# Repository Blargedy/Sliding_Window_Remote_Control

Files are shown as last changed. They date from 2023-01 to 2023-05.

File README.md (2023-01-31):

# Sliding Window Remote Control
WIP



### BoM
* linear actuator x1
* L298N H-bridge motor driver x1 [Amazon](https://www.amazon.ca/gp/product/B07D1HP3SJ/ref=ppx_yo_dt_b_search_asin_title?ie=UTF8&psc=1)
* 12v power supply with 5.5mm barrel jack x1 [Amazon](https://www.amazon.ca/gp/product/B085ZZ86ZJ/ref=ppx_yo_dt_b_search_asin_title?ie=UTF8&psc=1)
* limit switch x1 [Amazon](https://www.amazon.ca/gp/product/B07YKH3TDR/ref=ppx_yo_dt_b_search_asin_title?ie=UTF8&psc=1)
* SPST-mom button x1 [Amazon](https://www.amazon.ca/gp/product/B07Q6C3NSN/ref=ppx_yo_dt_b_search_asin_title?ie=UTF8&psc=1)
* Panic cutoff button x1 [Amazon](https://www.amazon.ca/gp/product/B07WTL3KPB/ref=ppx_yo_dt_b_search_asin_title?ie=UTF8&psc=1)
* SPDT-mom switch x1 [Amazon](https://www.amazon.ca/gp/product/B01LYGWWHA/ref=ppx_yo_dt_b_search_asin_title?ie=UTF8&psc=1)
* SPDT-latching switch x1 [Amazon](https://www.amazon.ca/gp/product/B01BTTOEQ6/ref=ppx_yo_dt_b_search_asin_title?ie=UTF8&psc=1)
* 5.5mm x 2.1mm barrel jack connector [Amazon](https://www.amazon.ca/gp/product/B092Z6ZG3V/ref=ppx_yo_dt_b_search_asin_title?ie=UTF8&psc=1)
* power button x1 [Amazon](https://www.amazon.ca/gp/product/B08225LGRT/ref=ppx_yo_dt_b_search_asin_title?ie=UTF8&psc=1)
* 12v A4x20 fan x1 [Amazon](https://www.amazon.ca/gp/product/B071W93333/ref=ppx_yo_dt_b_search_asin_title?ie=UTF8&psc=1)
* panic button x1 [Amazon](https://www.amazon.ca/gp/product/B07WTL3KPB/ref=ppx_yo_dt_b_search_asin_title?ie=UTF8&psc=1)
* Arduino Wemos D1 Mini x1 [Amazon](https://www.amazon.ca/gp/product/B07WWFND3B/ref=ppx_yo_dt_b_search_asin_title?ie=UTF8&psc=1)
* 2 port wago x1
* 3 port wago x1
* 5 port wago x2
* 2 port microfit-3 connectors and crimps x2
* Dupont headers and crimps
* ferrule crimps
* M3 hardware
* M3 heat inserts (4mmH x 5mmD) x4
* wires

## Part printing
Clearances were designed for ABS/ASA shrinkages, but the parts can be made of basically any filament

## Electronics
1. solder and crimp electric box
2. Crimp linear actuator



## Software Configuration
1. Install arduino ide
2. Download  Wemos drivers from https://www.wemos.cc/en/latest/ch340_driver.html
3. Create a new folder somewhere and extract the contents of the driver zip into this new folder
4. run `SETUP.EXE`
5. Click on `INSTALL`



6. In arduino IDE click on `File` then `Prefereces...`



7. under `Additional Boards Manager URLs:` paste ```http://arduino.esp8266.com/stable/package_esp8266com_index.json```



8. Click on `Sketch`, then `Include Library` then `Manage Libraries`, or press the key combination `Ctr+Shift+I`.



9. Search for a library called `ESP8266 microgear` and click `INSTALL`.



10. Click on `Tools`, then `Board` then `Board Manager` or press the key combination `Ctr+Shift+B`.



11. Search for `ESP8266` and install the board



12. Make sure the switch that controls the motor driver 5v supply is shut off and/or you unplug the unit, or you'll damage the driver or your pc or both

13. Plug in the D1 mini with a micro-usb cable

14. Click on `Select Board` and select the `Unknown COMx`.



15. Search for `d1` and select `LOLIN(WEMOS) D1 R2 & mini`



16. Copy the folder `wifi_passwords` to your arduino library folder (under `Documents > Arduino > libraries` by default)



17. Edit wifi_passwords.h to fill in your wifi name and password, replacing the text and the <> but leaving the " ".

18. Upload Actuator_Control_Module.ino to the D1 Mini via USB



19. Adjust the pin number definitions if you made any changes to the default. 

20. Unplug the D1 from your computer, plug in the 12v PSU to the unit, and flip the internal power connection switch.

21. Go to `https://www.python.org/downloads/` and click `Download Python 2.7.18`. 



22. Run the python installer and follow the prompts.

24. Restart Arduino IDE.

25. Check your firewall settings to make sure the OTA connection isn't being blocked. I had to set my network to private for OTA to work. 

26. If all went well you should see the OTA connection come up as an upload target option.



27. Once you upload the sketch you will have to restart the IDE to be able to upload again. This bug should be fixed soon<sup>TM</sup>

## Hardware
1. Mount linear actuator

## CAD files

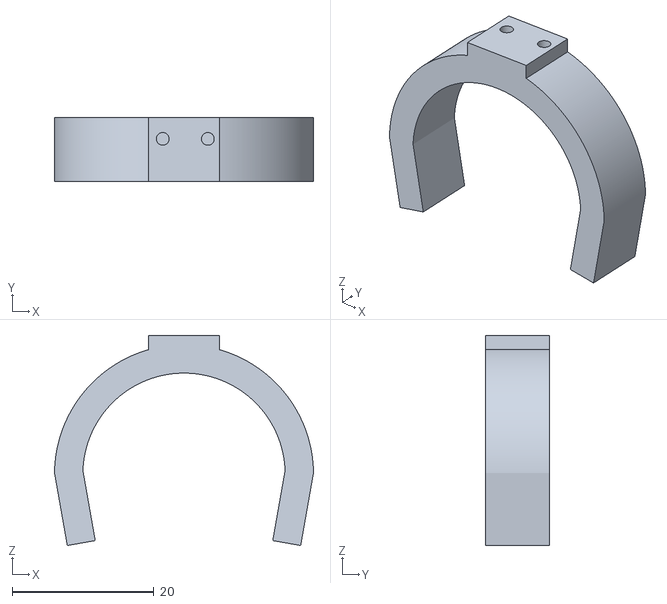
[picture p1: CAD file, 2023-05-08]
STLs/Endstop Switch Collar.stl
36.5 x 9.00 x 29.6

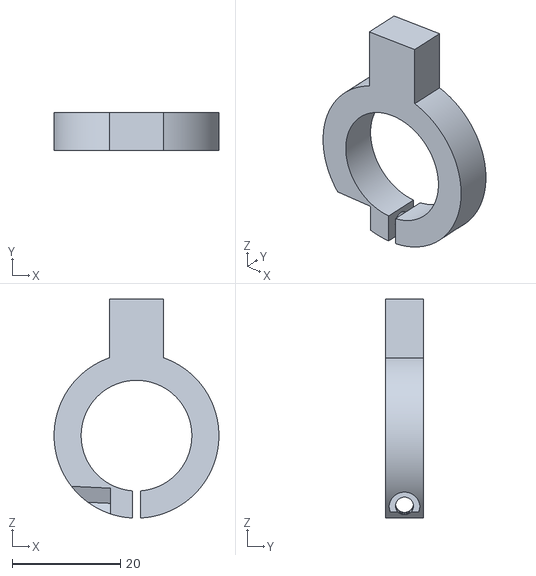
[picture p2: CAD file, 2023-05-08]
STLs/Endstop Paddle Collar.stl
30.4 x 7.00 x 40.4

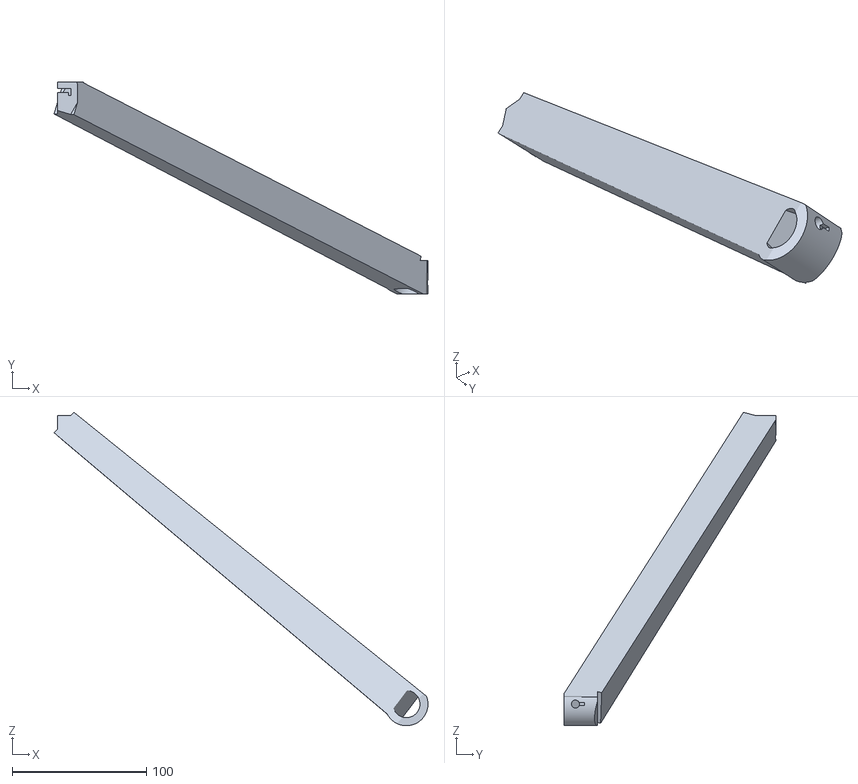
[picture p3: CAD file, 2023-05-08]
STLs/Window Arm.stl
278.8 x 158.0 x 233.6

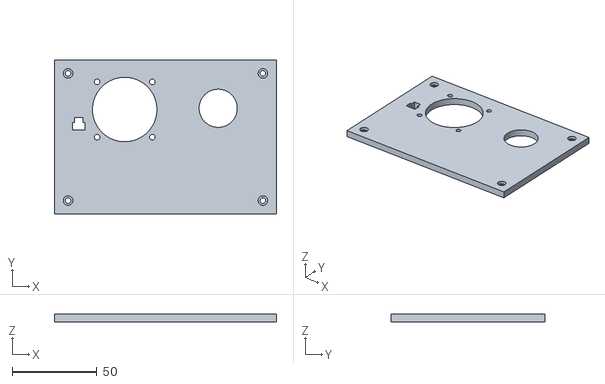
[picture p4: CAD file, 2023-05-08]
STLs/Enclosure_Lid.stl
131.0 x 91.0 x 4.50

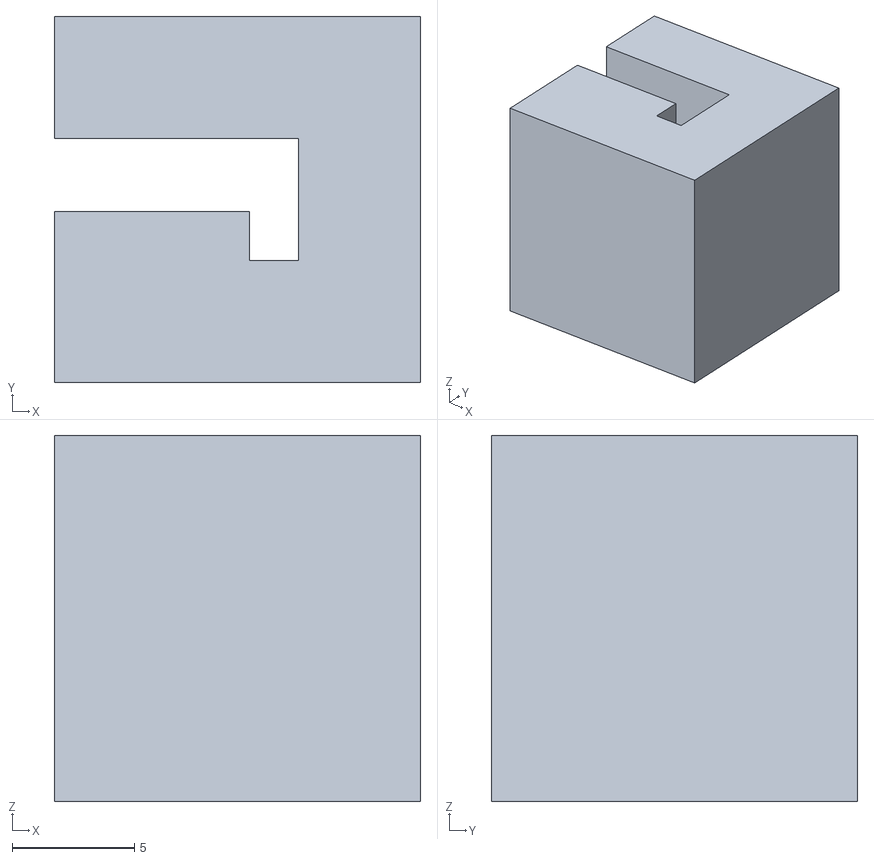
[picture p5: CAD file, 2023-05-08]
STLs/Window Clamp.stl
15.0 x 15.0 x 15.0

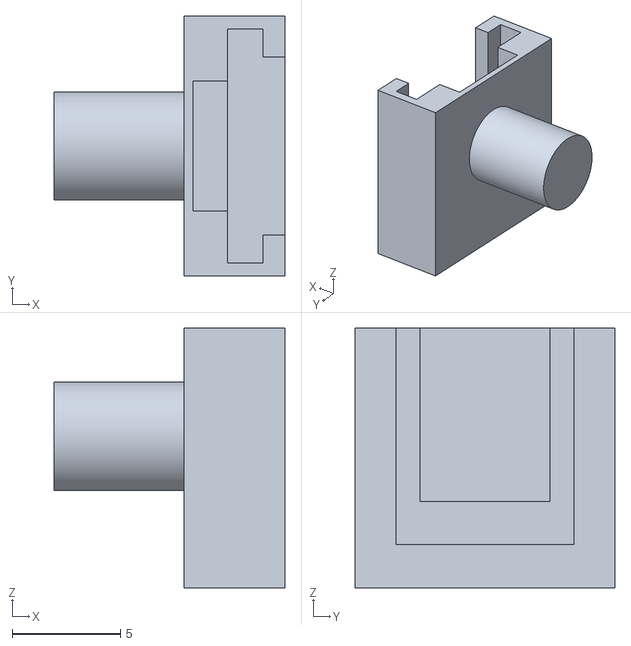
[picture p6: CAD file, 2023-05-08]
STLs/LED_Diffuser.stl
10.6 x 12.0 x 12.0

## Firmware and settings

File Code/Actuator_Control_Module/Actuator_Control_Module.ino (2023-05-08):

#include <ESP8266WiFi.h>
#include <ESP8266mDNS.h>
#include <WiFiUdp.h>
#include <ArduinoOTA.h>
#include <wifi_passwords.h>
#include <Adafruit_NeoPixel.h>
#ifdef __AVR__
 #include <avr/power.h> // Required for 16 MHz Adafruit Trinket
#endif

const char* ssid = STASSID;
const char* password = STAPSK;

// PINS 
// using D3 or D4 caused me problems
const int mom_close_pin = D1;
const int mom_open_pin = D2;
const int endstop_pin = D6;
const int motor_close_pin = D5;
const int motor_open_pin = D0;
const int LED_pin = D4;

Adafruit_NeoPixel pixel(1, LED_pin, NEO_GRBW + NEO_KHZ800);

// Variables
const float piston_speed = 0.01;          //in m/s (coincidentally also mm/ms)
const float time_to_energize_coils = 1;   //in ms
bool position_known = false;              //true if position is known
float current_position = -1;              //in mm
const int minimum_allowable_position = 0;
const int maximum_allowable_position = 350;

void setup() {
  pixel.begin();
  pixel.clear();
  pixel.setPixelColor(0, pixel.Color(150,0,0,0));
  pixel.show();
  //pin modes
  //pinMode(LED_BUILTIN, OUTPUT);
  pinMode(mom_close_pin, INPUT_PULLUP);
  pinMode(mom_open_pin, INPUT_PULLUP);
  pinMode(endstop_pin, INPUT_PULLUP);
  pinMode(motor_close_pin, OUTPUT);
  pinMode(motor_open_pin, OUTPUT);

  //start by stopping all motor movement
  digitalWrite(motor_close_pin, LOW);
  digitalWrite(motor_open_pin, LOW);

  Serial.begin(115200);
  Serial.println("Booting");
  WiFi.mode(WIFI_STA);
  WiFi.begin(ssid, password);
  while (WiFi.waitForConnectResult() != WL_CONNECTED) {
    Serial.println("Connection Failed! Rebooting...");
    delay(5000);
    ESP.restart();
  }

  ArduinoOTA.onStart([]() {
    String type;
    if (ArduinoOTA.getCommand() == U_FLASH) {
      type = "sketch";
    } else {  // U_FS
      type = "filesystem";
    }

    // NOTE: if updating FS this would be the place to unmount FS using FS.end()
    Serial.println("Start updating " + type);
  });
  ArduinoOTA.onEnd([]() {
    Serial.println("\nEnd");
  });
  ArduinoOTA.onProgress([](unsigned int progress, unsigned int total) {
    Serial.printf("Progress: %u%%\r", (progress / (total / 100)));
  });
  ArduinoOTA.onError([](ota_error_t error) {
    Serial.printf("Error[%u]: ", error);
    if (error == OTA_AUTH_ERROR) {
      Serial.println("Auth Failed");
    } else if (error == OTA_BEGIN_ERROR) {
      Serial.println("Begin Failed");
    } else if (error == OTA_CONNECT_ERROR) {
      Serial.println("Connect Failed");
    } else if (error == OTA_RECEIVE_ERROR) {
      Serial.println("Receive Failed");
    } else if (error == OTA_END_ERROR) {
      Serial.println("End Failed");
    }
  });
  ArduinoOTA.begin();
  Serial.println("Ready");
  Serial.print("IP address: ");
  Serial.println(WiFi.localIP());
  
  home();
}

void loop() {  
  //to do:
  //measure piston speed precisely
  //measure charge time
  //check if endstop opened without piston being moved
  //panic if endstop pin still triggered after opening
  //panic if endstop doesn't trigger after full movement
  //sanity check movement commands to not go out of range of motion
  //wirelessly send debug messages
  //program alarm bell  
  //control via home assistant
  ArduinoOTA.handle();

  if(position_known){
    Serial.print("position is known and is: ");
    Serial.println(current_position);
  }
  else{
    Serial.println("position is not known");
  }
  check_manual_switches();
  delay(500);
}

// I kept getting the polarity of the endstop check wrong
// Endstop switch is normally closed and connected to ground
// when endstop gets triggered the pin is pulled high by internal resistor
bool query_endstop(){
  return(digitalRead(endstop_pin));
}

void home(){
  if(query_endstop()){
    Serial.println("already homed");
    position_known = true;
    current_position = 0;
    return;
  }
  else{
    Serial.println("homing");
    digitalWrite(motor_close_pin, HIGH);
    while(!query_endstop()){
      delay(5);
    }
    digitalWrite(motor_close_pin,LOW);
    position_known = true;
    current_position = 0;
    Serial.println("homed");
    return;
  } 
}

void check_manual_switches(){
  //check open switch
  if(!digitalRead(mom_open_pin)){  //toggle switch triggered
    Serial.println("opening");
    digitalWrite(motor_open_pin, HIGH);
    delay(time_to_energize_coils + 50);       //wait for debounce
    current_position += 50*piston_speed;
    while(!digitalRead(mom_open_pin)){      
      delay(100);
      current_position += 100*piston_speed;
    }
    digitalWrite(motor_open_pin, LOW);    
    Serial.println("stopped");
  }
  //check close switch
  if(!digitalRead(mom_close_pin)){  //toggle switch triggered
    Serial.println("closing");
    digitalWrite(motor_close_pin, HIGH);
    delay(time_to_energize_coils + 50);       //wait for debounce
    current_position -= 50*piston_speed;
    while(!digitalRead(mom_close_pin)){      
      delay(100);
      current_position -= 100*piston_speed;
    }
    digitalWrite(motor_close_pin, LOW);    
    Serial.println("stopped");
  }
  return;
}

void go_to_x(int desired_position){
  if(desired_position < minimum_allowable_position || desired_position > maximum_allowable_position){
    Serial.println("DESIRED POSITION OUT OF BOUNDS");
  }
  int rounded_current_position = (int)roundf(current_position);
  if(rounded_current_position == desired_position){
    Serial.println("close enough.jpg");
    return;
  }
  else{
    Serial.print("moving to ");
    Serial.println(desired_position);
    int distance_in_mm_to_move = desired_position - rounded_current_position;
    int time_in_ms_to_move = ((int) ((float)abs(distance_in_mm_to_move))/piston_speed*1000);
    if(distance_in_mm_to_move > 0){
      digitalWrite(motor_open_pin, HIGH);
      delay(time_in_ms_to_move);
      digitalWrite(motor_open_pin, LOW);
      return;
    }
    else{
      digitalWrite(motor_close_pin, HIGH);
      delay(time_in_ms_to_move);
      digitalWrite(motor_close_pin, LOW);
      return;
    }
  }
}

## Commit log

2021-11-08 initial commit of actuator code
2021-11-08 add v1 of rear mount
2021-11-08 add v2 rear mount and new front mount
2023-01-27 redid lost work on enclosure. Get OTA programming to work
    [Enclosure_Lid.stl]
2023-01-30 adjusted air holes and lid fan connector location
    [Enclosure_Lid.stl]
2023-01-31 move button checking to function and add move_to_x (untested)
2023-02-02 add label for motor and endstop
2023-05-08 update lid, add endstop, experimental arm
    [Enclosure_Lid.stl, Endstop Paddle Collar.stl, Endstop Switch Collar.stl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]
2023-05-08 adjust fitement of switch collar
    [Endstop Switch Collar.stl]
